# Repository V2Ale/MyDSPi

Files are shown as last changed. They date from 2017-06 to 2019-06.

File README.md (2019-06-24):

<!DOCTYPE html PUBLIC "-//W3C//DTD HTML 4.01//EN" "http://www.w3.org/TR/html4/strict.dtd">
<html>
<head>
  <meta content="text/html; charset=ISO-8859-1"
 http-equiv="content-type">
  <h1>MyDSPi</h1>
</head>
<body>

<br>
<div style="margin-left: 40px;">MyDSPi is an easy to
implement solution for audio processing and amplification with a
Raspberry Pi (2 and 3) audio output. <br>
It's intended to be a cost effective solution to make
active&nbsp;speakers.<br>
Electronic circuit is based on Analog Device ADAU1701 DSP and Texas
Instrument TPA3118 amplifier.<br>
<br>
More information  avaialble at <a href="http://mydspi;v2ale.com/?utm_source=Github&utm_medium=Link&utm_campaign=mainpage" >mydspi.v2ale.com</a>
<br>
</div>
<br style="font-weight: bold;">
<h3>Hardware description</h3>
<h4 style="margin-left: 40px; width: 1239px;">Overview : </h4>
<div style="margin-left: 40px;"><br>
<div style="margin-left: 40px;">MyDSPi is designed to be
compact and mounted over a Raspberry Pi 2 board. Hardware is split over
2 printed circuit boards stack one above the other.<br><br>
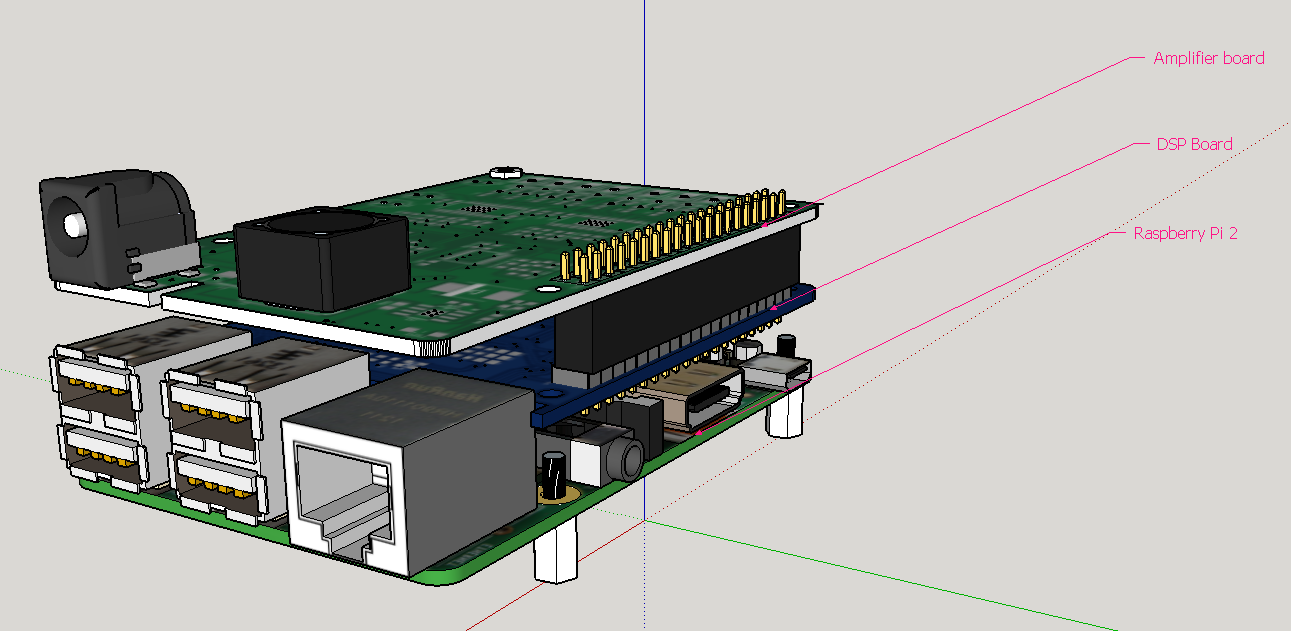
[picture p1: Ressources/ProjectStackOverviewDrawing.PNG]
Block diagram Amplifier
<br>
<br>
The first board is dedicated to DSP processing and Digital to Analog
signal convertion from Raspberry Pi audio output.&nbsp;Audio must
be output from Raspberry
Pi through I2S output pins.<br>
DSP is controlled by Raspberry Pi using I2C&nbsp; interface and
requires no
advanced DSP programming to have signal processed and can be easily
configured by editing a configuration file.<br>
The DSP work at fixed sampling frequency of 48000 Hz. <br>
Output channels are transmitted to the amplifier board through I2S
protocol.<br>
<br>
The second board host Digital to Analog converter that feed the
amplifier with analog signal for amplification. Power supply input
circuit is also located on this PCB, which can accept any supply
voltage from 12 to 24 volts to feed all system power supply (including
the Raspberry Pi).<br>
<br>
For more details about each board, please refer to :<br><br>
<ul>
<li><a href="https://github.com/V2Ale/MyDSPi/tree/master/Electronic/DSP%20Board/2.0">DSP Board page</a></li>
<li><a href="https://github.com/V2Ale/MyDSPi/tree/master/Electronic/Amplification%20Board">Amplifier board page</a></li>
</ul>
</div>
</div>
<br>
<h3><big>Software description</big></h3>
<div style="margin-left: 40px;">Once install is done the
MyDSPi software run at start-up to load default DSP parameters and then
load the parameters read from the configuration file.<br>
<br>
</div>
<h4>DSP Capabilities description</h4>
<br>
<div style="margin-left: 80px;">The default parameters of
the DSP are right now a 2 input / 2
output configuration with a default crossover and no EQ values loaded.
Parameter customization is done throught the MyDSPi.conf file and can
configure : <br>
<br>
<div style="margin-left: 40px;">- Input channels volume
controls<br>
- Input channels mute controls<br>
- 2 channels crossover<br>
- output channels Delay (up to 412 samples) <br>
- Ouput channel mute control<br>
- Ouput channel phase control<br>
- Output channel volume control<br>
</div>
</div>
<br>
<h3>Installation</h3>
Installation of &nbsp;MyDSPi is tested and developped for Linux
Raspbian Jessie distribution.<br>
<br>
The following step describes only the installation major steps. <br>

<ul>
<li>Setup I2C (<a href="https://learn.adafruit.com/adafruits-raspberry-pi-lesson-4-gpio-setup/configuring-i2c">
https://learn.adafruit.com/adafruits-raspberry-pi-lesson-4-gpio-setup/configuring-i2c</a>)<br>
</li>
<li>Setup I2S soundcard (following &nbsp;<a href="https://www.hifiberry.com/build/documentation/hifiberry-software-configuration/">https://www.hifiberry.com/build/documentation/hifiberry-software-configuration/</a>)<br>
</li>
<li>
 Run installation script (see https://github.com/V2Ale/MyDSPi/tree/master/Software/Install)<br>
 </li>
 </ul>

<h3>Configuration</h3>
To edit the configuration file, use the command :<br>
<pre>&nbsp;sudo nano /etc/default/MyDSPi.conf</pre>
For more details about configuration file rules, please refer to <span
 style="color: red;">https://github.com/V2Ale/MyDSPi/tree/master/Software/Install/config</span><br>
<br>
<h3>Roadmap</h3>
Support 5.1 configuration<br>
Support 7.1 configuration<br>
Support quadriphonic configuration<br>
&nbsp;<br>

</body>
</html>

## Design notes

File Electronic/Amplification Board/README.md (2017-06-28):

<!DOCTYPE html PUBLIC "-//W3C//DTD HTML 4.01//EN" "http://www.w3.org/TR/html4/strict.dtd">
<html>
<head>
  <meta content="text/html; charset=ISO-8859-1"
 http-equiv="content-type">
</head>
<body>
<h1>Amplifier and Power Supply Board</h1>
<h3>Overview</h3>
<br>
Amplifier and Power Supply board is the second PCB of this project that
can be stack with the DSP board. It's designed to host 2 set of
amplifiers and DAC, which can handle up to for 4 channels of
amplification. In addition, the board is used for power supply the
entire stack. <br>
<br style="color: red;">
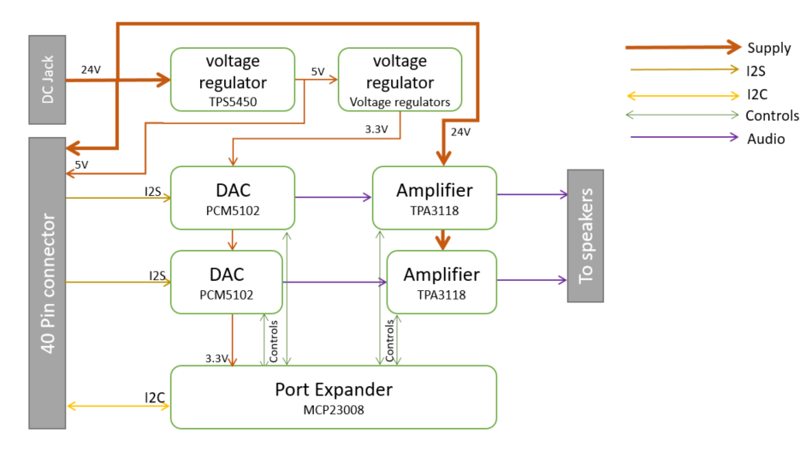
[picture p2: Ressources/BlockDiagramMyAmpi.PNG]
Block diagram Amplifier
<span style="color: red;"></span><br>
<br>
<h3>DAC</h3>
<br>
Digital to Analog conveters used for this board are PCM5102a (and
similar such as PCM5100). The
benefit of using PCM5102 DAC is that it does not requires the I2S
high frequency system clock (SCK) to work making routing between boards
much easier. <br>
Also, this component provides additionnal controls like demphasis, FIR
or IIR filter of output, format (I2S or Left justified) and soft mute.
Those controls are driven by a port expander with I2C interface that
allows end user to use this amplifier board for other designs. More
details on those controls can be found in the component datasheet. <br>
Last, this component
is readily cheap and available on the market (PCM5100 being pin to pin
compatible).<br>
<br>
<br>
<h3>Amplifier</h3>
&nbsp;<br>
The Texas Instrument TPA3118 amplifiers are stereo class D amplifiers
that can drive 2x30W into 8 Ohms load (with a 24V supply). It can
operate with a wide single operating voltage from 4.5V to 26V keeping
the power supply design simple. <br>
As audio input, the amplifier expect single ended audio which are
provided by DAC. All external controls (like gain) of the amplifier are
set constant except the amplifier mute which can be controlled thanks
to the port expander.<br>
Last, the amplifier integrates bad operating conditions (like
overtemperature, output short circuit) which are sent back to the
Faultz pins. Those pins are connected to the port expander and can be
monitored as well.<br>
<br>
<h3>Port Expander</h3>
<br>
As explain in previous parts, the port expander is in charge of
monitoring amplifier state and set DAC and amplifiers controls. The
part used for this task is very common MCP23008 from Microchip.<br>
<br>
<h3>Power Supply </h3>
<br>
The board do not have any power supply transformer and switch mode
power supply block design is outside the scope of this project. As a
result, a maximum of 26V voltage is expected at the DC jack terminal
connector. This voltage is directly used to feed the amplifiers and is
also converted down to a 5V supply voltage for all other boards
(including Raspberry Pi supply). &nbsp; <br>
<br>
<h3>Connectors </h3>
<br>
The&nbsp; 40 pin connector is used to connected to the DSP board
and get DSP output channels,&nbsp; I2C and amplifier mute command.
It also provides the supply rail voltage for the entire project.<br>
<br>
<span style="color: red;">[IMAGE DU SCHEMA DU CONNETEUR]</span><br>
<br>
<table style="text-align: left; width: 378px; height: 1216px;"
 border="1" cellpadding="2" cellspacing="2">
  <tbody>
    <tr>
      <td>Pin</td>
      <td>Name &nbsp; &nbsp; </td>
      <td>Description &nbsp; &nbsp; &nbsp; &nbsp;
&nbsp;</td>
    </tr>
    <tr>
      <td>1</td>
      <td>DC In</td>
      <td>Input Power supply is duplicated on this pin</td>
    </tr>
    <tr>
      <td>2</td>
      <td>DC In</td>
      <td>Input Power supply is duplicated on this pin</td>
    </tr>
    <tr>
      <td>3</td>
      <td>-</td>
      <td>Not used</td>
    </tr>
    <tr>
      <td>4</td>
      <td>SCL</td>
      <td>I2C Clock</td>
    </tr>
    <tr>
      <td>5</td>
      <td>-</td>
      <td>Not used</td>
    </tr>
    <tr>
      <td>6</td>
      <td>SDA</td>
      <td>I2C Data</td>
    </tr>
    <tr>
      <td>7</td>
      <td>Amp_mute</td>
      <td>Pin connected to Raspberry pi and amplifier mute pin.</td>
    </tr>
    <tr>
      <td>8</td>
      <td>-</td>
      <td>Not used</td>
    </tr>
    <tr>
      <td>9</td>
      <td>-</td>
      <td>Not used</td>
    </tr>
    <tr>
      <td>10</td>
      <td>-</td>
      <td>Not used</td>
    </tr>
    <tr>
      <td>11</td>
      <td>GND</td>
      <td>Ground</td>
    </tr>
    <tr>
      <td>12</td>
      <td>-</td>
      <td>Not used</td>
    </tr>
    <tr>
      <td>13</td>
      <td>-</td>
      <td>Not used</td>
    </tr>
    <tr>
      <td>14</td>
      <td>-</td>
      <td>Not used</td>
    </tr>
    <tr>
      <td>15</td>
      <td>-</td>
      <td>Not used</td>
    </tr>
    <tr>
      <td>16</td>
      <td>-</td>
      <td>Not used</td>
    </tr>
    <tr>
      <td>17</td>
      <td>GPO3</td>
      <td>DSP MPIO3 Output pin</td>
    </tr>
    <tr>
      <td>18</td>
      <td>GPO2</td>
      <td>DSP&nbsp;MPIO2 Output pin</td>
    </tr>
    <tr>
      <td>19</td>
      <td>GPO1</td>
      <td>DSP&nbsp;MPIO1 Output pin</td>
    </tr>
    <tr>
      <td>20</td>
      <td>DSPIN_SADATA0</td>
      <td>DSP I2S input pin 1</td>
    </tr>
    <tr>
      <td>21</td>
      <td>DSP_SDATA0</td>
      <td>DSP I2S output pin 1</td>
    </tr>
    <tr>
      <td>22</td>
      <td>DSP_BCK</td>
      <td>DSP I2S Bitclock output</td>
    </tr>
    <tr>
      <td>23</td>
      <td>DSP_SDATA1</td>
      <td>DSP I2S output pin 2</td>
    </tr>
    <tr>
      <td>24</td>
      <td>DSP_LRCK</td>
      <td>DSP I2S Bitclock output</td>
    </tr>
    <tr>
      <td>25</td>
      <td>ANALOG_IN_R</td>
      <td>DSP Analog input pin 1</td>
    </tr>
    <tr>
      <td>26</td>
      <td>ANALOG_IN_L</td>
      <td>DSP Analog input pin 2</td>
    </tr>
    <tr>
      <td>27</td>
      <td>AUDIO_OUT0</td>
      <td>DSP Analog output 1</td>
    </tr>
    <tr>
      <td>28</td>
      <td>GPO9</td>
      <td>DSP MPIO 9</td>
    </tr>
    <tr>
      <td>29</td>
      <td>AUDIO_OUT1</td>
      <td>DSP Analog output 2</td>
    </tr>
    <tr>
      <td>30</td>
      <td>GPO8</td>
      <td>DSP MPIO 8</td>
    </tr>
    <tr>
      <td>31</td>
      <td>AUDIO_OUT2</td>
      <td>DSP Analog output 3</td>
    </tr>
    <tr>
      <td>32</td>
      <td>AUDIO_OUT3</td>
      <td>DSP Analog output 4</td>
    </tr>
    <tr>
      <td>33</td>
      <td>-</td>
      <td>Not used</td>
    </tr>
    <tr>
      <td>34</td>
      <td>-</td>
      <td>Not used</td>
    </tr>
    <tr>
      <td>35</td>
      <td>GND</td>
      <td>Ground</td>
    </tr>
    <tr>
      <td>36</td>
      <td>GND</td>
      <td>Ground</td>
    </tr>
    <tr>
      <td>37</td>
      <td>5V</td>
      <td>5V power supply</td>
    </tr>
    <tr>
      <td>38</td>
      <td>GND</td>
      <td>Ground</td>
    </tr>
    <tr>
      <td>39</td>
      <td>5V</td>
      <td>5V power supply</td>
    </tr>
    <tr>
      <td>40</td>
      <td>5V</td>
      <td>5V power supply</td>
    </tr>
  </tbody>
</table>
<br>
<br>
</body>
</html>

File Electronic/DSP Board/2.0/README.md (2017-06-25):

DSP PCB

Power Supply

The PCB receives its power supply from the amplifier PCB which has the input DC jack socket and DC converters.

The 5V supply at input  is shared with the Raspberry Pi. From this supply, a 3.3V regulator on the board feed all components of this board.

Input channels
The DSP can process analog or digital (I2S) input, but only analog circuit is made available. Despite the presence of analog input circuit components routed in the 40 pin connecor, the project do not rely on it.
To use the board with the Raspberry Pi, the 3 wires of I2S are converted by a DAC (PCM5102a) and provided to DSP by the analog input.
The benefit of using PCM5102 DAC is that it does not requires the I2S system clock (SCK) to work. It's especially useful because the raspberry pi does not provide the SCK out of the box and it avoids useless painful struggle with the kernel.
Moreover, this component is readily cheap and available on the market (PCM5100 being pin to pin compatible). Extra functionality of this DAC such as filter type or soft mute are not used and not left to end user.

Output channels
 
The DSP can output analog or digital (I2S) signals. Both of them are available on this board but the amplifiers board is expecting I2S signal before amplification stage. If you whish to use the I2S output with other amplifier board, please mind that it does not output the SCK as well. This choice has been made because the DAC do not need it to operate normally and it avoid special care in the routing for this high speed clock.

I2S and clocks

Input and output I2S signals are working at fixed LRCK of 48kHz. The DSP is driven by a 24.576MHz clock. I2S LRCK and BCK at input and output of the DSP are connected together as required in the datasheet of the component.
It's not possible to run the DSP at other sampling frequency or with different outside clock without changing the routing of the board.

Connectors

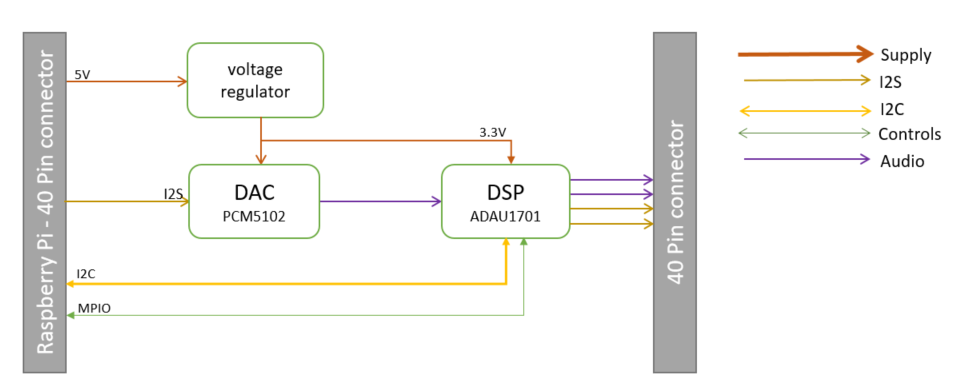
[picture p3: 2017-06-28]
Ressources/BlockDiagramMyDSPi.PNG

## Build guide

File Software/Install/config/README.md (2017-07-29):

Configuration
----------

MyDSPi configuration files needs to respect a few rules to allow to correct parameter loading.
All parametes are grouped into sections. Each sections can define a set of parameters which have their respective values. 

**Block diagram**

The audio block are linked together as follow to build the audio chain :

	audioinput -> input mute -> input volume -> EQ -> crossover -> delay -> phase -> mute -> volume

**Rules**
Writting a configuration needs to respect the following rules

 1.  Comments are ignored from the configuration lines.
 2.  A comment is everything that is after ';'character
 3.  A section is written in between brackets as    [SECTION]
 4.  To be valid a parameter must be followed by a value as parameter = value
 5.  Section, parameters and values must respect letter case
 6.  Each set of  parameter and its value must be written on the same line

**Sections**
The available sections are :

    [config]
    [Input1]
    [Input2]
    [Output1
    [Output2]
    [EQ1]
    [crossover]

----------

**Config section**

The input section is used to configure the input type of the DSP. It has one parameter : *audioinput*

It can take the following values

| Parameter | Value | Description  |
| --- | ---- | --- |
| audioinput | *digital* |  set DSP input to I2S signal|
| audioinput | *analog* | set DSP input to analog|
| audioinput | *tone* | This  force the input to be a twin sine tone signal (500 Hz and 5000 Hz)|

**Input sections**
There is one input section per input channel with 2 parameters in each section.

| Parameter | Value | Description  |
| --- | ---- | --- |
| *mute* | 0 or 1|  muted when it's value is 1, must be 0 otherwise|
| *volume* | -80.0 to 0.0|  control the input volume of the channel|

**Output sections**
There is one output section per output channel with 4 parameters in each section.

| Parameter | Value | Description  |
| --- | ---- | --- |
| *mute* | 0 or 1|  muted when it's value is 1, must be 0 otherwise|
| *volume* | -80.0 to 0.0|  control the input volume of the channel|
| *delay* | 1 to 412|  control the delay in samples of this channel |
| *phase*| 0 or 1|  control the output channel polarity. 1 to reverse polarity, 0 otherwise|

**EQ sections**
There are 14 EQ filters avaialble which can be configured independently. 

HSF for high shelf filter
LSF for low shelf filter
HPF for high pass filter (1st order Bessel)
LPF for Low pass filter (1st order Bessel)
peak for peak filter (parametric)

| Parameter | Value | Description  |
| --- | ---- | --- |
| *type* | HSF or LSF or HPF or LPF or peak| Defines the type of EQ |
| *F* | 20 to 20000| Set the corner frequency of the filter|
| *B* | -80.0 to 20.0|  Control boost factor of  peak, LSF and HSF filters.  |
| *Q* | 0.1 to 10.0|  Control Q-factor of  peak type EQ  |
| *B*| 0.0 to 3.0|  Control the S parameter of LSF and HSF filters.

**Crossover section**
       There is one crossover for both output channels made of 2nd order butterworth low-pass and high-pass filter.   
       
| Parameter | Value | Description  |
| --- | ---- | --- |
| *FLow* | between 20 and 20000 |  Defines the Low pass filter corner frequency. It must be lower than the FHigh value |
| *FHigh* | between 20 and 20000 |  Defines the High pass filter corner frequency. It must be greater than the FLow value

----------
**Config file Example**

	[config]

	audioinput=digital									

	[Input1]

	mute=1

	volume=-25										

	[Input2]										

	mute=0												

	volume=-25											

	[Output2]											

	phase=-1

	mute=1												

	delay=1												

	volume=0											

	[Output1]											

	phase=1

	mute=1												

	delay=1												

	volume=-6											

	[EQ1]												

	F=125												

	B=-2.8												

	Q=1.41													

	Type=peak											

	[EQ2]

	F=5000												

	B=-2												

	Q=4													

	Type=peak	

	[EQ3]

	F=2200

	B=-2

	S=2

	Type=HSF

	[crossover]											

	FLow = 2800										

	FHigh = 3000

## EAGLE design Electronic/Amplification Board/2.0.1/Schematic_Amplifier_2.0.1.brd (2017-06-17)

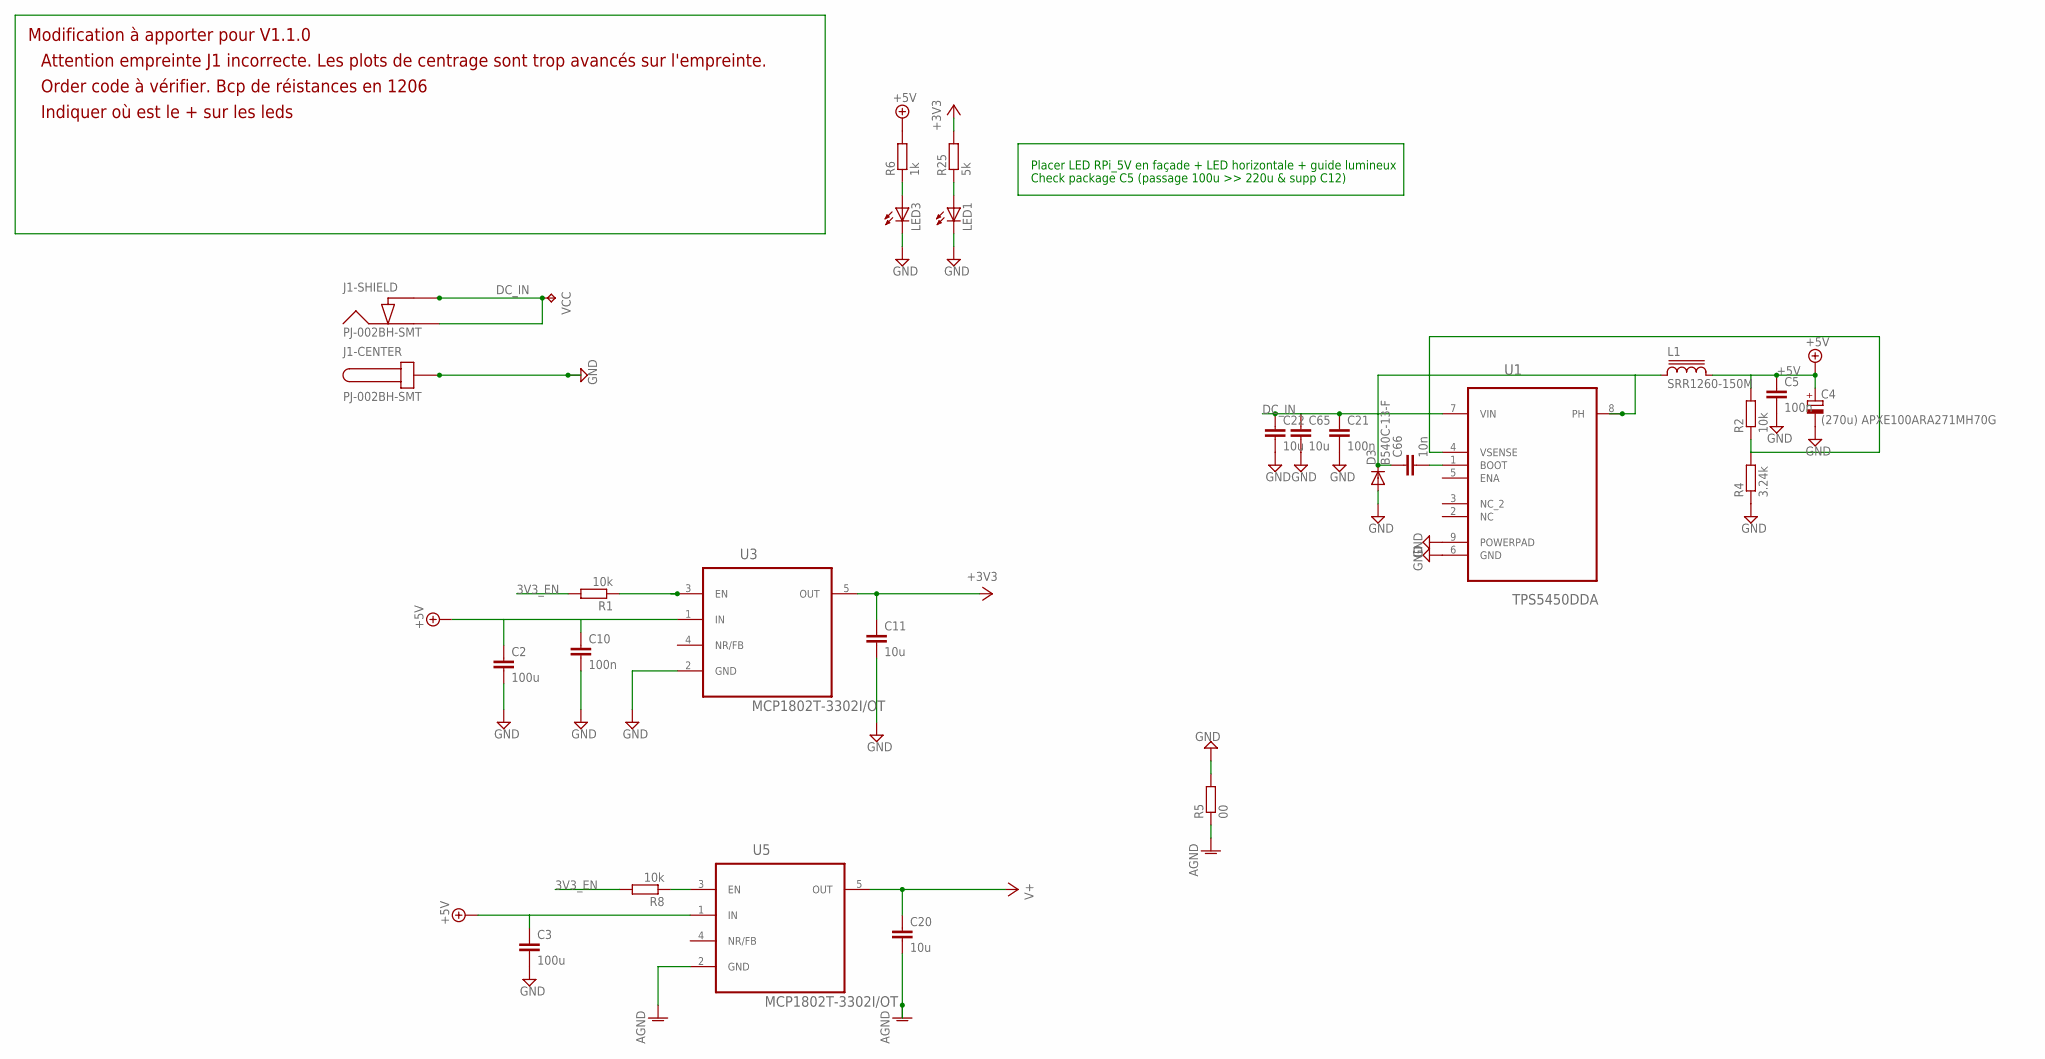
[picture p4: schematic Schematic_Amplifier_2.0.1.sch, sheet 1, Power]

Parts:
C2, C3: 100u; C1206
C4: (270u) APXE100ARA271MH70G; 175TMP-0810
C5, C10, C21: 100n; C0603
C11, C20, C22, C65: 10u; C0805
C66: 10n; C0603
D3: B540C-13-F; SMC
J1: PJ-002BH-SMT; 002BH-SMT
L1: SRR1260-150M; SRR1280
LED1: LEDSML0603; SML0603
LED3: LEDSML1206; SML1206
R1, R2, R8: 10k; R0603
R4: 3.24k; R0603
R5: 00; R0603
R6: 1k; R0603
R25: 5k; R0603
U1: TPS5450DDA; SOIC127P600X170-9N
U3, U5: MCP1802T-3302I/OT; SOT95P280X145-5N
VCC: TPTP20R; TP20R

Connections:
3V3_EN: R1.2, R8.2; also elsewhere on the board
+3V3: C11.1, R25.2, U3.5 (OUT); also elsewhere on the board
+5V: C2.1, C3.1, C4.+, C5.1, C10.1, L1.2, R2.2, R6.2, U3.1 (IN), U5.1 (IN); also elsewhere on the board
AGND: C20.2, R5.1, U5.2 (GND); also elsewhere on the board
DC_IN: C21.1, C22.1, C65.1, J1.2, J1.3, U1.7 (VIN), VCC.TP; also elsewhere on the board
GND: C2.2, C3.2, C4.-, C5.2, C10.2, C11.2, C21.2, C22.2, C65.2, D3.A, J1.CENTER1 (1), J1.CENTER2 (1), LED1.C, LED3.C, R4.1, R5.2, U1.6 (GND), U1.9 (POWERPAD), U3.2 (GND); also elsewhere on the board
unnamed: R1.1, U3.3 (EN)
unnamed: LED1.A, R25.1
unnamed: C66.2, U1.1 (BOOT)
unnamed: LED3.A, R6.1
unnamed: R8.1, U5.3 (EN)
unnamed: C66.1, D3.C, L1.1, U1.8 (PH)
unnamed: R2.1, R4.2, U1.4 (VSENSE)
V+: C20.1, U5.5 (OUT); also elsewhere on the board

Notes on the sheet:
Placer LED RPi_5V en façade + LED horizontale + guide lumineux
Check package C5 (passage 100u >> 220u & supp C12)
Attention empreinte J1 incorrecte. Les plots de centrage sont trop avancés sur l'empreinte.
Modification à apporter pour V1.1.0
Order code à vérifier. Bcp de réistances en 1206
Indiquer où est le + sur les leds

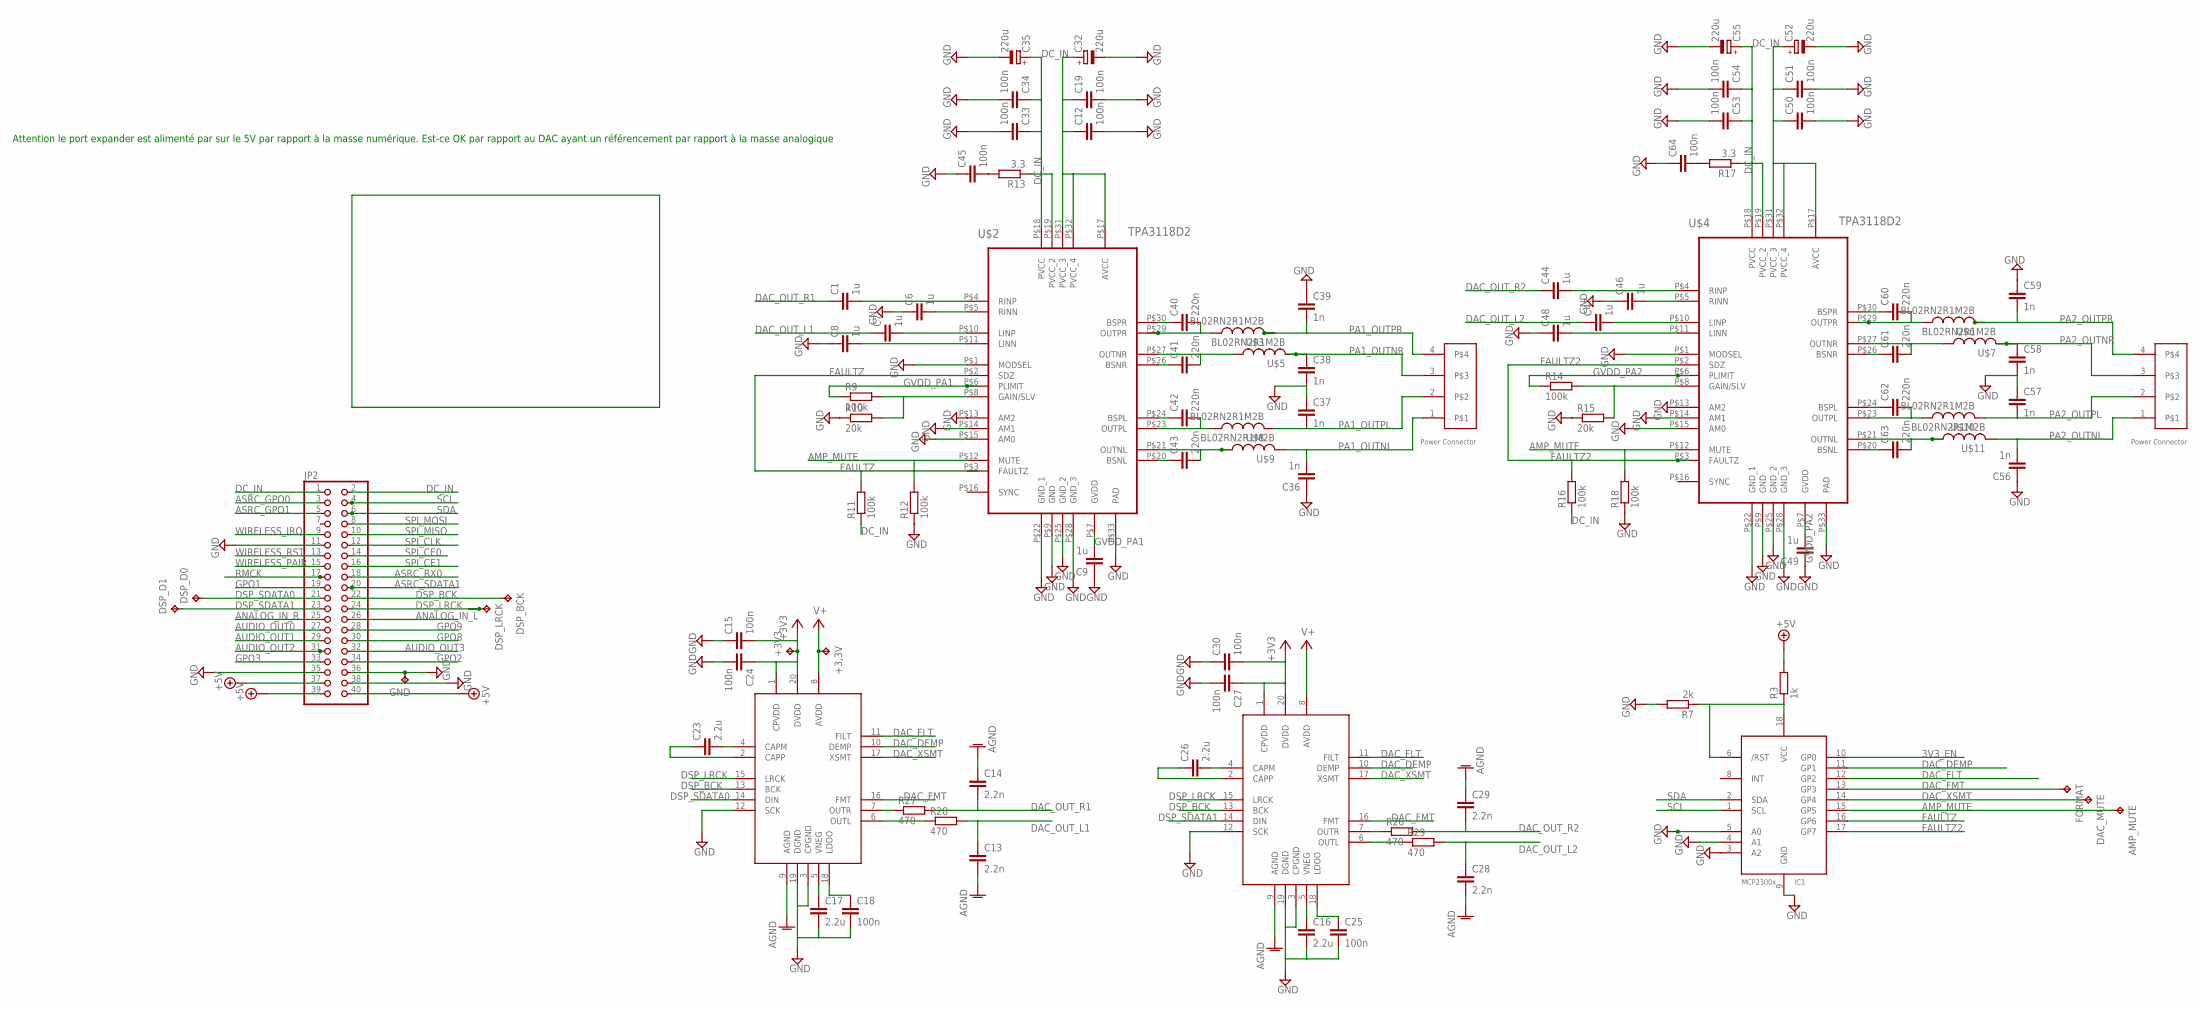
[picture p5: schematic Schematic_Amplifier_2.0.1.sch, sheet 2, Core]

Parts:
+3,3V, +3V3: TPTP10R; TP10R
AMP_MUTE: TPTP08R; TP08R
C1, C6, C7, C8, C9, C44, C46, C47, C48, C49: 1u; C0603
C12, C15, C18, C19, C24, C25, C27, C30, C33, C34, C45, C50, C51, C53, C54, C64: 100n; C0603
C13, C14, C28, C29: 2.2n; C0603
C16, C17, C23, C26: 2.2u; C0603
C32, C35, C52, C55: 220u; E2,5-6
C36, C37, C38, C39, C56, C57, C58, C59: 1n; C0603
C40, C41, C42, C43, C60, C61, C62, C63: 220n; C0603
DAC0, DAC1: PCM5102A; 20L-TSSOP
DAC_MUTE: TPTP08R; TP08R
DSP_BCK: TPTP08R; TP08R
DSP_D0, DSP_D1: TPTP08R; TP08R
DSP_LRCK: TPTP08R; TP08R
FORMAT: TPTP08R; TP08R
GND: TPTP19SQ; TP19SQ
IC1: MCP23008/SO; SO18W
JP2: PINHD-2X20; 2X20
R3: 1k; R0603
R7: 2k; R0603
R9, R11, R12, R14, R16, R18: 100k; R0603
R10, R15: 20k; R0603
R13, R17: 3.3; R0603
R26, R27, R28, R29: 470; R0603
U$1, U$12: 1-1123723-4; POWER_CON_HEADER
U$2, U$4: TPA3118D2; TSSOP32
U$3, U$5, U$6, U$7, U$8, U$9, U$10, U$11: BL02RN2R1M2B; FB

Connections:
3V3_EN: IC1.10 (GP0); also elsewhere on the board
$OUTR: DAC0.7 (OUTR), R26.1
+3V3: +3V3.TP, C15.2, C24.1, C27.1, C30.2, DAC0.1 (CPVDD), DAC0.20 (DVDD), DAC1.1 (CPVDD), DAC1.20 (DVDD); also elsewhere on the board
+5V: JP2.37, JP2.39, JP2.40, R3.2; also elsewhere on the board
AGND: C13.2, C14.1, C28.2, C29.1, DAC0.9 (AGND), DAC1.9 (AGND); also elsewhere on the board
AMP_MUTE: AMP_MUTE.TP, IC1.15 (GP5), R12.2, R18.2, U$2.P$12 (MUTE), U$4.P$12 (MUTE)
ANALOG_IN_L: JP2.26
ANALOG_IN_R: JP2.25
ASRC_GPO0: JP2.3
ASRC_GPO1: JP2.5
ASRC_RX0: JP2.18
ASRC_SDATA1: JP2.20
AUDIO_OUT0: JP2.27
AUDIO_OUT1: JP2.29
AUDIO_OUT2: JP2.31
AUDIO_OUT3: JP2.32
DAC_DEMP: DAC0.10 (DEMP), DAC1.10 (DEMP), IC1.11 (GP1)
DAC_FLT: DAC0.11 (FILT), DAC1.11 (FILT), IC1.12 (GP2)
DAC_FMT: DAC0.16 (FMT), DAC1.16 (FMT), FORMAT.TP, IC1.13 (GP3)
DAC_OUT_L1: C7.1, C13.1, R28.2
DAC_OUT_L2: C28.1, C47.1, R29.2
DAC_OUT_R1: C1.1, C14.2, R27.2
DAC_OUT_R2: C29.2, C44.1, R26.2
DAC_XSMT: DAC0.17 (XSMT), DAC1.17 (XSMT), DAC_MUTE.TP, IC1.14 (GP4)
DC_IN: C12.1, C19.1, C32.+, C33.1, C34.1, C35.+, C50.1, C51.1, C52.+, C53.1, C54.1, C55.+, JP2.1, JP2.2, R11.1, R13.1, R16.1, R17.1, U$2.P$17 (AVCC), U$2.P$18 (PVCC), U$2.P$31 (PVCC_3), U$2.P$32 (PVCC_4), U$4.P$17 (AVCC), U$4.P$18 (PVCC), U$4.P$31 (PVCC_3), U$4.P$32 (PVCC_4); also elsewhere on the board
DSP_BCK: DAC0.13 (BCK), DAC1.13 (BCK), DSP_BCK.TP, JP2.22
DSP_LRCK: DAC0.15 (LRCK), DAC1.15 (LRCK), DSP_LRCK.TP, JP2.24
DSP_SDATA0: DAC1.14 (DIN), DSP_D0.TP, JP2.21
DSP_SDATA1: DAC0.14 (DIN), DSP_D1.TP, JP2.23
FAULTZ: IC1.16 (GP6), R11.2, U$2.P$2 (SDZ), U$2.P$3 (FAULTZ)
FAULTZ2: IC1.17 (GP7), R16.2, U$4.P$2 (SDZ), U$4.P$3 (FAULTZ)
GND: C6.1, C8.1, C9.1, C12.2, C15.1, C16.2, C17.2, C18.2, C19.2, C24.2, C25.2, C27.2, C30.1, C32.-, C33.2, C34.2, C35.-, C36.1, C37.1, C38.2, C39.1, C45.1, C46.1, C48.1, C49.1, C50.2, C51.2, C52.-, C53.2, C54.2, C55.-, C56.1, C57.1, C58.2, C59.1, C64.1, DAC0.3 (CPGND), DAC0.12 (SCK), DAC0.19 (DGND), DAC1.3 (CPGND), DAC1.12 (SCK), DAC1.19 (DGND), GND.TP, IC1.3 (A2), IC1.4 (A1), IC1.5 (A0), IC1.9 (GND), JP2.11, JP2.35, JP2.36, JP2.38, R7.2, R10.1, R12.1, R15.1, R18.1, U$2.P$1 (MODSEL), U$2.P$9 (GND), U$2.P$13 (AM2), U$2.P$14 (AM1), U$2.P$15 (AM0), U$2.P$22 (GND_1), U$2.P$25 (GND_2), U$2.P$28 (GND_3), U$2.P$33 (PAD), U$4.P$1 (MODSEL), U$4.P$9 (GND), U$4.P$13 (AM2), U$4.P$14 (AM1), U$4.P$15 (AM0), U$4.P$22 (GND_1), U$4.P$25 (GND_2), U$4.P$28 (GND_3), U$4.P$33 (PAD); also elsewhere on the board
GPO1: JP2.19
GPO2: JP2.34
GPO3: JP2.33
GPO8: JP2.30
GPO9: JP2.28
GVDD_PA1: C9.2, R9.1, U$2.P$6 (PLIMIT), U$2.P$7 (GVDD)
GVDD_PA2: C49.2, R14.1, U$4.P$6 (PLIMIT), U$4.P$7 (GVDD)
unnamed: C1.2, U$2.P$4 (RINP)
unnamed: IC1.6 (/RST), IC1.18 (VCC), R3.1, R7.1
unnamed: C6.2, U$2.P$5 (RINN)
unnamed: C7.2, U$2.P$10 (LINP)
unnamed: C8.2, U$2.P$11 (LINN)
unnamed: R9.2, R10.2, U$2.P$8 (GAIN/SLV)
unnamed: C41.2, U$2.P$27 (OUTNR), U$5.P$1 (1)
unnamed: C40.2, U$2.P$29 (OUTPR), U$3.P$1 (1)
unnamed: C42.2, U$2.P$23 (OUTPL), U$8.P$1 (1)
unnamed: C43.2, U$2.P$21 (OUTNL), U$9.P$1 (1)
unnamed: C44.2, U$4.P$4 (RINP)
unnamed: C40.1, U$2.P$30 (BSPR)
unnamed: C17.1, DAC1.5 (VNEG)
unnamed: C23.2, DAC1.4 (CAPM)
unnamed: C45.2, R13.2
unnamed: C46.2, U$4.P$5 (RINN)
unnamed: C47.2, U$4.P$10 (LINP)
unnamed: C41.1, U$2.P$26 (BSNR)
unnamed: C42.1, U$2.P$24 (BSPL)
unnamed: C43.1, U$2.P$20 (BSNL)
unnamed: C48.2, U$4.P$11 (LINN)
unnamed: DAC1.7 (OUTR), R27.1
unnamed: DAC1.6 (OUTL), R28.1
unnamed: C16.1, DAC0.5 (VNEG)
unnamed: C25.1, DAC0.18 (LDOO)
unnamed: C26.2, DAC0.4 (CAPM)
unnamed: C18.1, DAC1.18 (LDOO)
unnamed: C26.1, DAC0.2 (CAPP)
unnamed: R14.2, R15.2, U$4.P$8 (GAIN/SLV)
unnamed: C23.1, DAC1.2 (CAPP)
unnamed: DAC0.6 (OUTL), R29.1
unnamed: C61.2, U$4.P$27 (OUTNR), U$7.P$1 (1)
unnamed: C60.2, U$4.P$29 (OUTPR), U$6.P$1 (1)
unnamed: C62.2, U$4.P$23 (OUTPL), U$10.P$1 (1)
unnamed: C63.2, U$4.P$21 (OUTNL), U$11.P$1 (1)
unnamed: C60.1, U$4.P$30 (BSPR)
unnamed: C61.1, U$4.P$26 (BSNR)
unnamed: C62.1, U$4.P$24 (BSPL)
unnamed: C63.1, U$4.P$20 (BSNL)
unnamed: C64.2, R17.2
PA1_OUTNL: C36.2, U$1.1, U$9.P$2 (2)
PA1_OUTNR: C38.1, U$1.3, U$5.P$2 (2)
PA1_OUTPL: C37.2, U$1.2, U$8.P$2 (2)
PA1_OUTPR: C39.2, U$1.4, U$3.P$2 (2)
PA2_OUTNL: C56.2, U$11.P$2 (2), U$12.1
PA2_OUTNR: C58.1, U$7.P$2 (2), U$12.3
PA2_OUTPL: C57.2, U$10.P$2 (2), U$12.2
PA2_OUTPR: C59.2, U$6.P$2 (2), U$12.4
RMCK: JP2.17
SCL: IC1.1 (SCL), JP2.4
SDA: IC1.2 (SDA), JP2.6
SPI_CE0: JP2.14
SPI_CE1: JP2.16
SPI_CLK: JP2.12
SPI_MISO: JP2.10
SPI_MOSI: JP2.8
V+: +3,3V.TP, DAC0.8 (AVDD), DAC1.8 (AVDD); also elsewhere on the board
WIRELESS_IRQ: JP2.9
WIRELESS_PAIR: JP2.15
WIRELESS_RST: JP2.13

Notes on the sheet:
Attention le port expander est alimenté par sur le 5V par rapport à la masse numérique. Est-ce OK par rapport au DAC ayant un référencement par rapport à la masse analogique

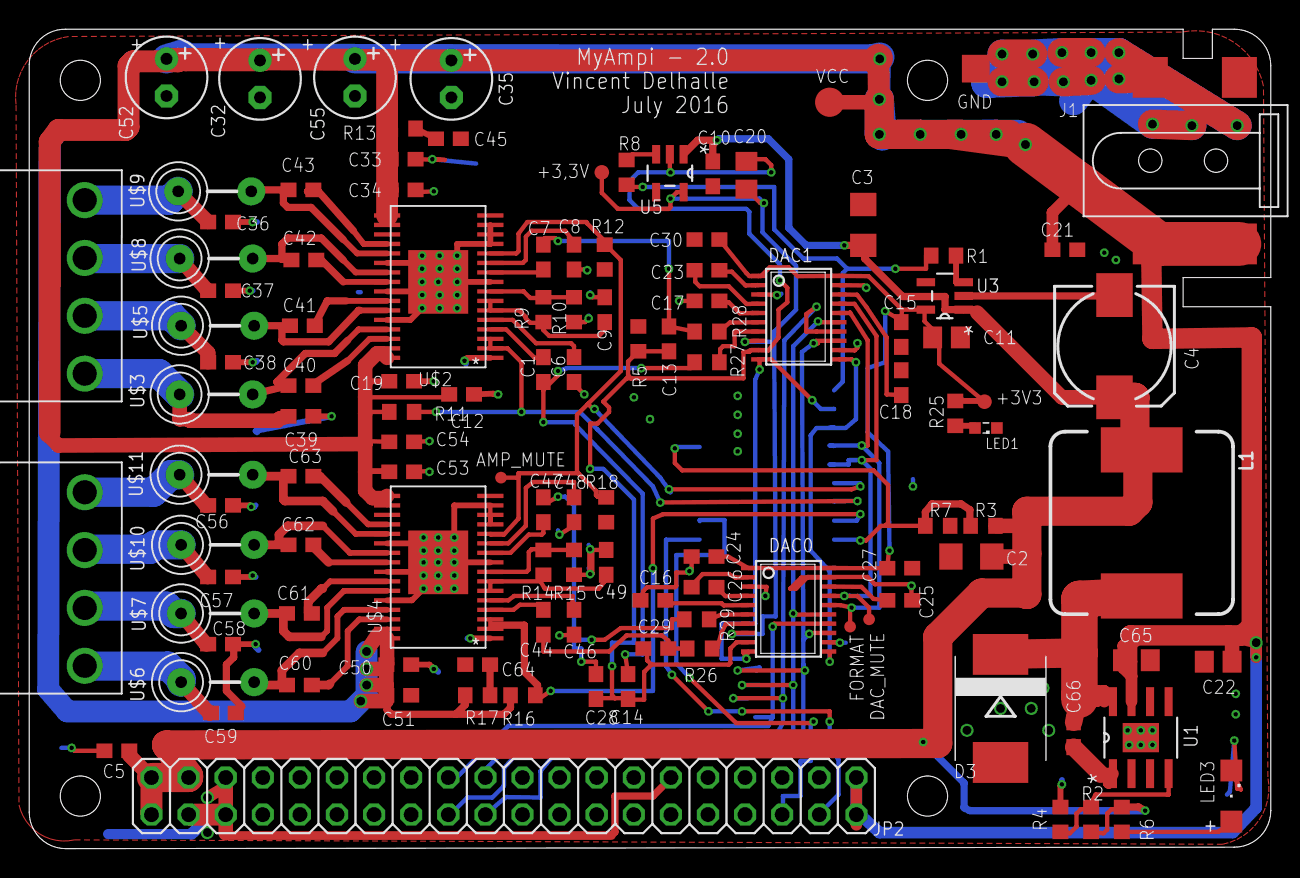
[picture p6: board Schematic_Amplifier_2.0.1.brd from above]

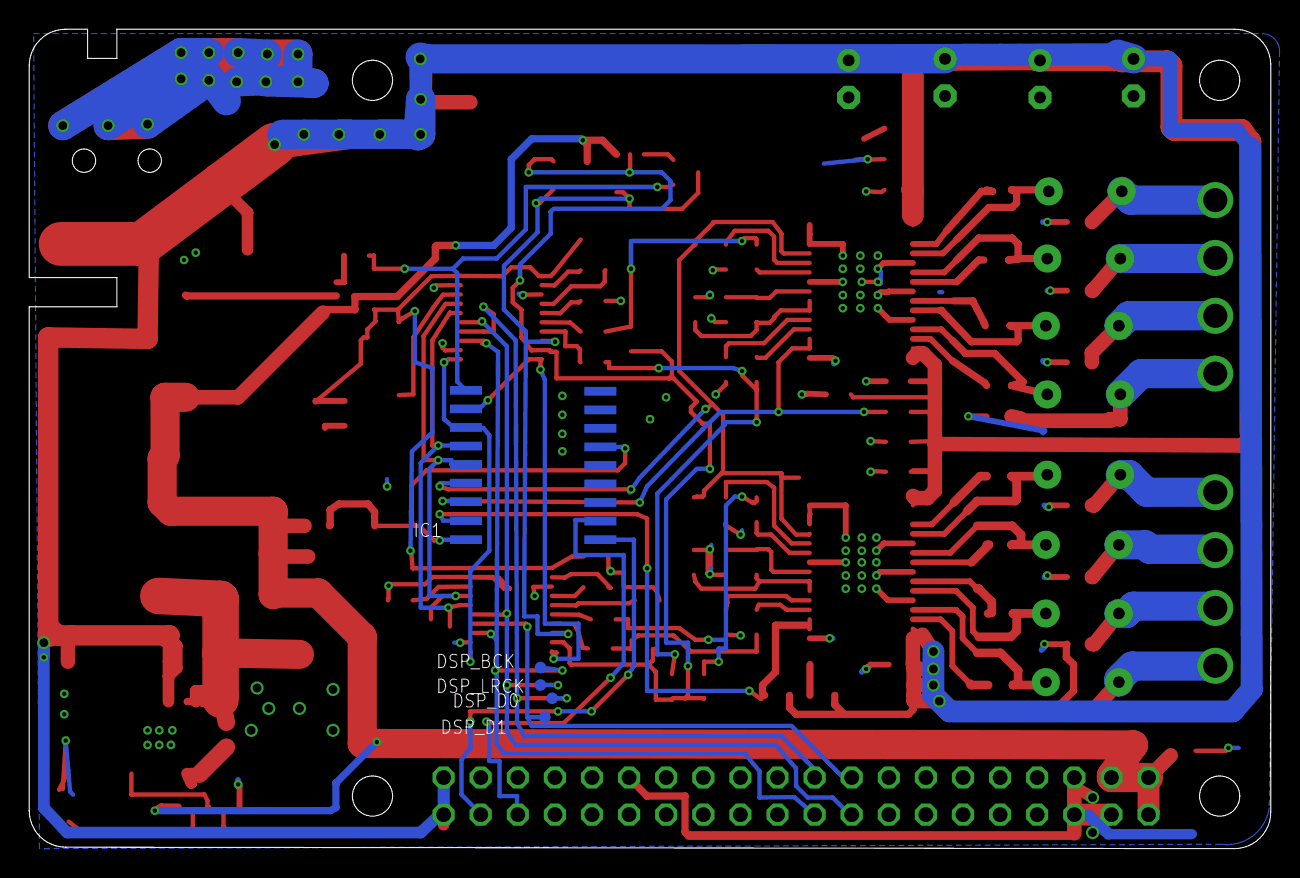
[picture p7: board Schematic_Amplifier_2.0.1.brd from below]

Board: 2 copper layers, 85.0 x 56.1 mm, 123 parts (5 on the bottom side), 82 nets.

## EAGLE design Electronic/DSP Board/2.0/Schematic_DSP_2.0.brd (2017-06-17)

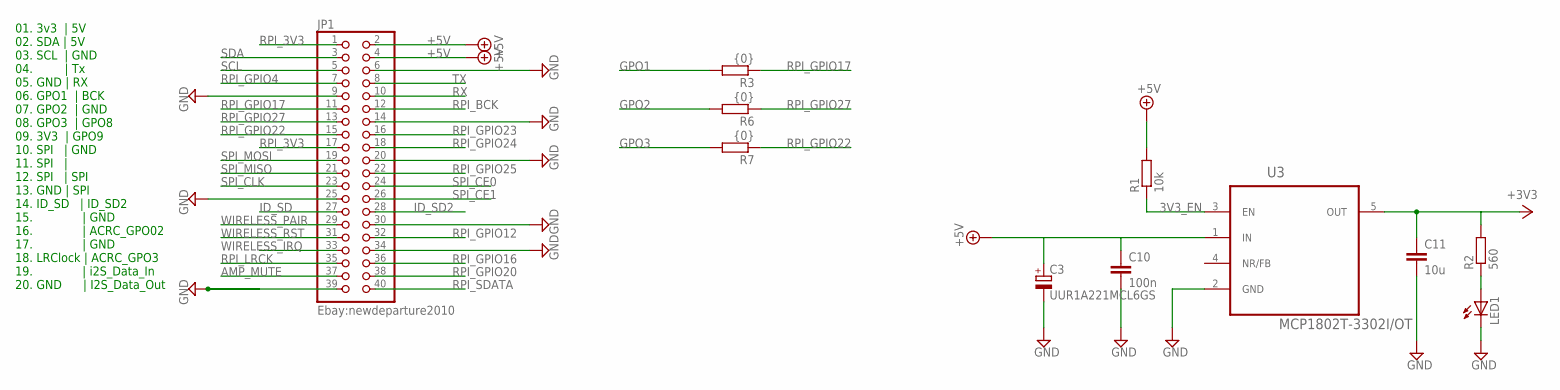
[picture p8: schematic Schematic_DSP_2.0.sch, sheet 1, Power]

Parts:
C3: UUR1A221MCL6GS; UD-6,3X7,7_NICHICON
C10: 100n; C0603
C11: 10u; C0805
JP1: Ebay:newdeparture2010; 2X20
LED1: LEDSML0603; SML0603
R1: 10k; R0603
R2: 560; R0603
R3, R6, R7: {0}; R0603
U3: MCP1802T-3302I/OT; SOT95P280X145-5N

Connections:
3V3_EN: R1.1, U3.3 (EN)
+3V3: C11.1, R2.2, U3.5 (OUT); also elsewhere on the board
+5V: C3.+, C10.1, JP1.2, JP1.4, R1.2, U3.1 (IN); also elsewhere on the board
AMP_MUTE: JP1.37; also elsewhere on the board
GND: C3.-, C10.2, C11.2, JP1.6, JP1.9, JP1.14, JP1.20, JP1.25, JP1.30, JP1.34, JP1.39, LED1.C, U3.2 (GND); also elsewhere on the board
GPO1: R3.2; also elsewhere on the board
GPO2: R6.2; also elsewhere on the board
GPO3: R7.2; also elsewhere on the board
ID_SD: JP1.27
ID_SD2: JP1.28
unnamed: LED1.A, R2.1
RPI_3V3: JP1.1, JP1.17
RPI_BCK: JP1.12; also elsewhere on the board
RPI_GPIO4: JP1.7
RPI_GPIO12: JP1.32
RPI_GPIO16: JP1.36
RPI_GPIO17: JP1.11, R3.1
RPI_GPIO20: JP1.38
RPI_GPIO22: JP1.15, R7.1
RPI_GPIO23: JP1.16
RPI_GPIO24: JP1.18
RPI_GPIO25: JP1.22
RPI_GPIO27: JP1.13, R6.1
RPI_LRCK: JP1.35; also elsewhere on the board
RPI_SDATA: JP1.40; also elsewhere on the board
RX: JP1.10
SCL: JP1.5; also elsewhere on the board
SDA: JP1.3; also elsewhere on the board
SPI_CE0: JP1.24
SPI_CE1: JP1.26
SPI_CLK: JP1.23
SPI_MISO: JP1.21
SPI_MOSI: JP1.19
TX: JP1.8
WIRELESS_IRQ: JP1.33
WIRELESS_PAIR: JP1.29
WIRELESS_RST: JP1.31

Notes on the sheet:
01. 3v3 | 5V 02. SDA | 5V 03. SCL | GND 04. | Tx 05. GND | RX 06. GPO1 | BCK 07. GPO2 | GND 08. GPO3 | GPO8 09. 3V3 | GPO9 10. SPI | GND 11. SPI | 12. SPI | SPI 13. GND | SPI 14. ID_SD | ID_SD2 15. | GND 16. | ACRC_GPO02 17. | GND 18. LRClock | ACRC_GPO3 19. | i2S_Data_In 20. GND | I2S_Data_Out

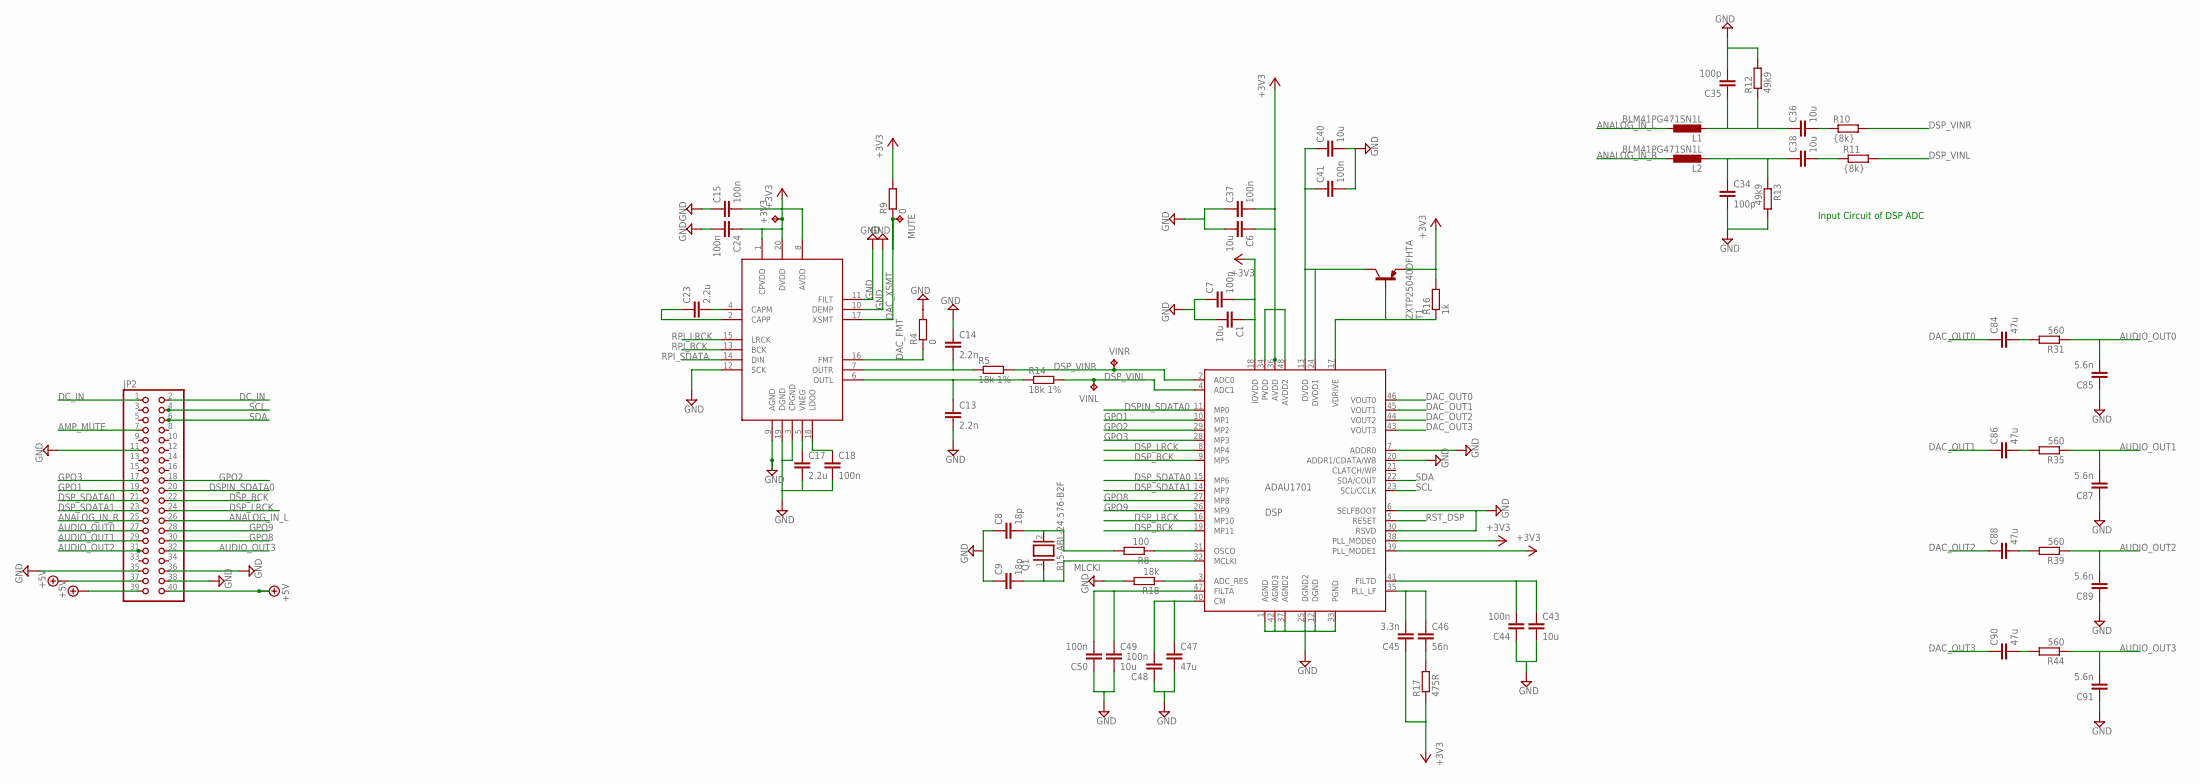
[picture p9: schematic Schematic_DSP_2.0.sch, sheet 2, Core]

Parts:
+3V3: TPTP10R; TP10R
C1, C6, C36, C38, C40, C43, C49: 10u; C0805
C7, C15, C18, C24, C37, C41, C44, C48, C50: 100n; C0603
C8, C9: 18p; C0603
C13, C14: 2.2n; C0603
C17, C23: 2.2u; C0603
C34, C35: 100p; C0603
C45: 3.3n; C0603
C46: 56n; C0603
C47, C84, C86, C88, C90: 47u; C0805
C85, C87, C89, C91: 5.6n; C0603
DAC1: PCM5102A; 20L-TSSOP
DSP: ADAU1701; PQFP48
JP2: PINHD-2X20; 2X20
L1, L2: BLM41PG471SN1L; L4532M
MUTE: TPTP10R; TP10R
Q1: 815-ABL-24.576-B2F; QS
R4, R9: 0; R0603
R5, R14: 18k 1%; R0603
R8: 100; R0603
R10, R11: {8k}; R0603
R12, R13: 49k9; R0603
R16: 1k; R0603
R17: 475R; R0603
R18: 18k; R0603
R31, R35, R39, R44: 560; R0603
T1: ZXTP25040DFHTA; SOT23-BEC
VINL: TPTP14R; TP14R
VINR: TPTP14R; TP14R

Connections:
+3V3: +3V3.TP, C1.1, C6.1, C7.2, C15.2, C24.1, C37.2, C45.1, DAC1.1 (CPVDD), DAC1.8 (AVDD), DAC1.20 (DVDD), DSP.18 (IOVDD), DSP.34 (PVDD), DSP.36 (AVDD), DSP.38 (PLL_MODE0), DSP.39 (PLL_MODE1), DSP.48 (AVDD2), R9.2, R16.2, R17.1, T1.E; also elsewhere on the board
+5V: JP2.37, JP2.39, JP2.40; also elsewhere on the board
AMP_MUTE: JP2.7; also elsewhere on the board
ANALOG_IN_L: JP2.26, L1.1
ANALOG_IN_R: JP2.25, L2.1
AUDIO_OUT0: C85.2, JP2.27, R31.1
AUDIO_OUT1: C87.2, JP2.29, R35.1
AUDIO_OUT2: C89.2, JP2.31, R39.1
AUDIO_OUT3: C91.2, JP2.32, R44.1
CM: C47.1, C48.2, DSP.40 (CM)
DAC_FMT: DAC1.16 (FMT), R4.1
DAC_OUT0: C84.1, DSP.46 (VOUT0)
DAC_OUT1: C86.1, DSP.45 (VOUT1)
DAC_OUT2: C88.1, DSP.44 (VOUT2)
DAC_OUT3: C90.1, DSP.43 (VOUT3)
DAC_OUTL: C13.1, DAC1.6 (OUTL), R14.1
DAC_OUTR: C14.2, DAC1.7 (OUTR), R5.1
DAC_XSMT: DAC1.17 (XSMT), MUTE.TP, R9.1
DC_IN: JP2.1, JP2.2
DSPIN_SDATA0: DSP.11 (MP0), JP2.20
DSP_BCK: DSP.9 (MP5), DSP.19 (MP11), JP2.22
DSP_LRCK: DSP.8 (MP4), DSP.16 (MP10), JP2.24
DSP_SDATA0: DSP.15 (MP6), JP2.21
DSP_SDATA1: DSP.14 (MP7), JP2.23
DSP_VINL: DSP.4 (ADC1), R11.2, R14.2, VINL.TP
DSP_VINR: DSP.2 (ADC0), R5.2, R10.2, VINR.TP
FILTA: C49.1, C50.2, DSP.47 (FILTA)
FILTD: C43.1, C44.2, DSP.41 (FILTD)
GND: C1.2, C6.2, C7.1, C8.1, C9.1, C13.2, C14.1, C15.1, C17.2, C18.2, C24.2, C34.2, C35.2, C37.1, C40.2, C41.2, C43.2, C44.1, C47.2, C48.1, C49.2, C50.1, C85.1, C87.1, C89.1, C91.1, DAC1.3 (CPGND), DAC1.9 (AGND), DAC1.10 (DEMP), DAC1.11 (FILT), DAC1.12 (SCK), DAC1.19 (DGND), DSP.1 (AGND), DSP.6 (SELFBOOT), DSP.7 (ADDR0), DSP.12 (DGND), DSP.20 (ADDR1/CDATA/WB), DSP.25 (DGND2), DSP.30 (RSVD), DSP.33 (PGND), DSP.37 (AGND2), DSP.42 (AGND3), JP2.11, JP2.35, JP2.36, JP2.38, R4.2, R12.2, R13.2, R18.2; also elsewhere on the board
GPO1: DSP.10 (MP1), JP2.19; also elsewhere on the board
GPO2: DSP.29 (MP2); also elsewhere on the board
GPO3: DSP.28 (MP3); also elsewhere on the board
GPO8: DSP.27 (MP8), JP2.30
GPO9: DSP.26 (MP9), JP2.28
MLCKI: C9.2, DSP.32 (MCLKI), Q1.1
unnamed: C40.1, C41.1, DSP.13 (DVDD), DSP.24 (DVDD1), T1.C
unnamed: DSP.31 (OSCO), R8.1
unnamed: DSP.17 (VDRIVE), R16.1, T1.B
unnamed: C8.2, Q1.2, R8.2
unnamed: C46.2, R17.2
unnamed: C17.1, DAC1.5 (VNEG)
unnamed: C23.2, DAC1.4 (CAPM)
unnamed: DSP.3 (ADC_RES), R18.1
unnamed: C36.2, R10.1
unnamed: C18.1, DAC1.18 (LDOO)
unnamed: C38.2, R11.1
unnamed: C23.1, DAC1.2 (CAPP)
unnamed: C34.1, C38.1, L2.2, R13.1
unnamed: C35.1, C36.1, L1.2, R12.1
unnamed: C84.2, R31.2
unnamed: C86.2, R35.2
unnamed: C88.2, R39.2
unnamed: C90.2, R44.2
PLL_LF: C45.2, C46.1, DSP.35 (PLL_LF)
RPI_BCK: DAC1.13 (BCK); also elsewhere on the board
RPI_LRCK: DAC1.15 (LRCK); also elsewhere on the board
RPI_SDATA: DAC1.14 (DIN); also elsewhere on the board
RST_DSP: DSP.5 (RESET)
SCL: DSP.23 (SCL/CCLK), JP2.4; also elsewhere on the board
SDA: DSP.22 (SDA/COUT), JP2.6; also elsewhere on the board

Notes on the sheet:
Input Circuit of DSP ADC

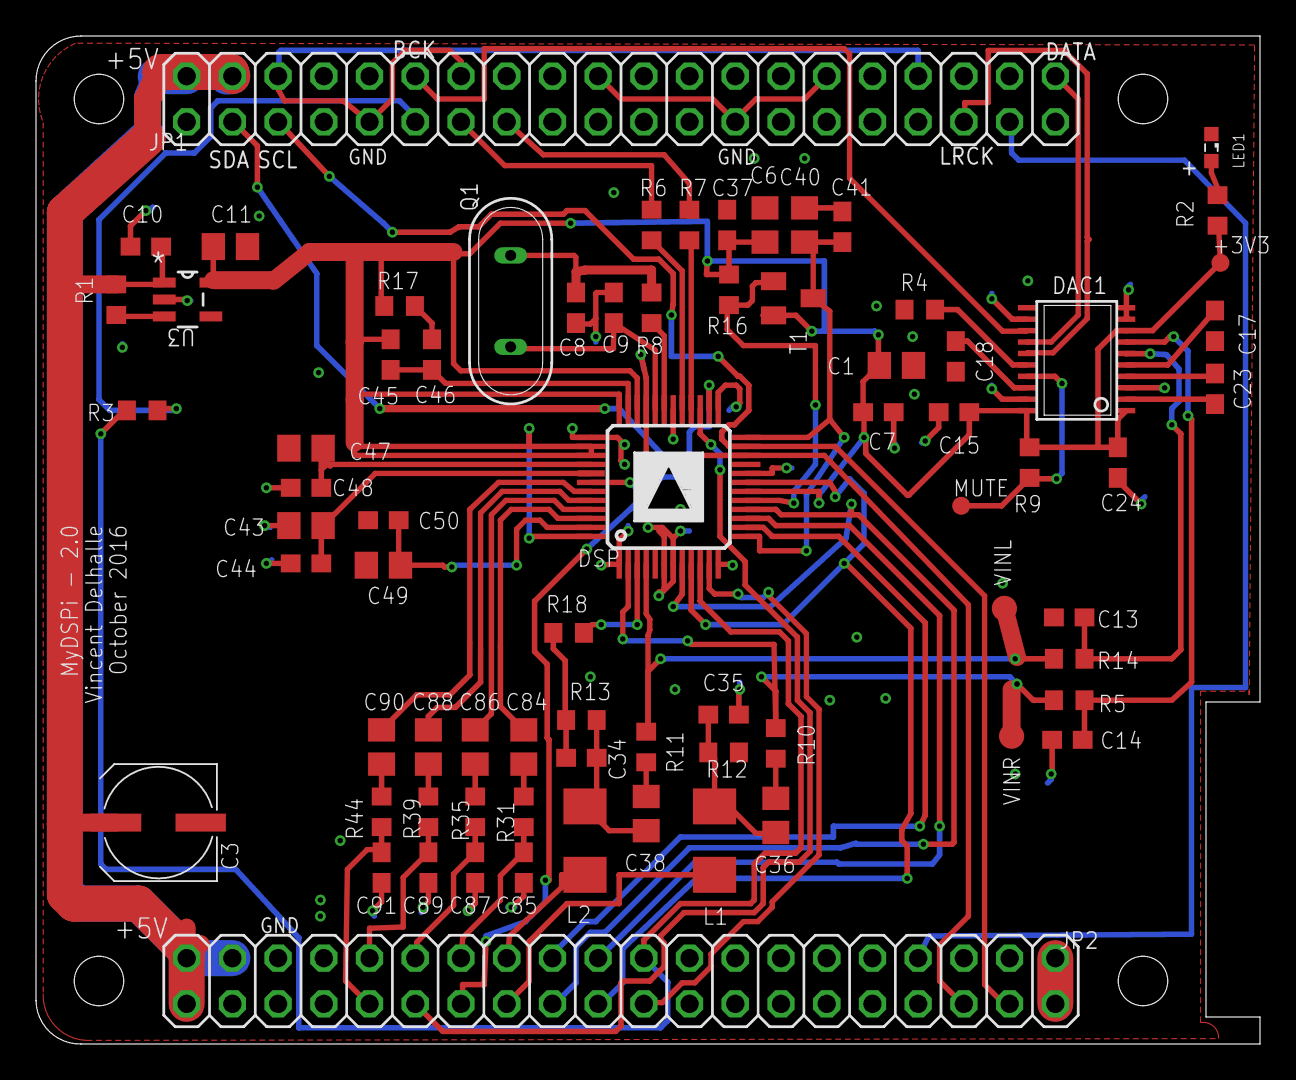
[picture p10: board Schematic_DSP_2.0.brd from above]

Board: 2 copper layers, 68.0 x 56.0 mm, 73 parts (0 on the bottom side), 65 nets.

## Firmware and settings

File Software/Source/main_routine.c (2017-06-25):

#include <stdio.h>
#include <fcntl.h>
#include <stdlib.h>
#include <unistd.h>
#include <sys/ioctl.h>
#include <string.h>
#include <errno.h>
#include <assert.h>
#include <sys/types.h>
#include <math.h>

//Error
#include "includes/error/error.h"

// Configuration
#include "config.h"

//I2C
#include <linux/i2c-dev.h>
#include "includes/libi2c/libi2c.h"

// DSP
#include "includes/Sigma/SS_MyDSPi_V122_IC_1.h"

#include "includes/Sigma/v122param.h"


#include "includes/DSP/DSPI2C.h"
#include "includes/DSP/DSPMath.h"

#include "includes/DSP/DSPDefine.h"
#include "includes/DSP/DSPBiquad.h"
#include "includes/Sigma/SigmaStudioFW.c"


//Ini manager

#include "includes/libini/libini.h"


#define PE_Address 0x40
#define DSP_Address 0x68

#define Master_Volume_Addr0 56
#define Master_Volume_Addr1 57
typedef unsigned long int UINT32;

#define PI 						3.141592654
#define Fs 						48000
#define MOD_CROSSOVER_20_ALG0_LOW_FILT1_PARAMB0_ADDR 90


void main(int argc, char *argv[])
{

struct f_return ret[5];
f_return i2cstatus;
f_return globalerr;



				 

printf("\n**********START Configuration of DSP *************\n");

i2cstatus = i2c_init("/dev/i2c-1");
	if(i2cstatus.errorstate !=-1)
	{
		//check device on i2c bus
		int i2cstatus = ADAU1701_Read_register(0x68,0x081C); 			
		if(i2cstatus>-1)
		{
		//Init DSP default values
		default_download_IC_1();


		int DSP_CORE_REG_VALUE = ADAU1701_Read_ConfigRegister(DSP_Address,0x081E);
		// printf("\n DSP CORE : 0x%X",DSP_CORE_REG_VALUE);
		

		/// To do: Mute all outputs and inputs
		//  

		// Check config file exist	
			FILE *fp;
			int filelenght;		
			char buffer[FILENAME_MAX];
			
			fp = fopen(config_file_path,"r");
			fread(buffer, filelenght, 1, fp); 
			
			if(fp == NULL)
			{
				globalerr = seterror(1,-1,"config file not found");
				exit(EXIT_FAILURE);
			}
			else
			{
				printf("\n Open config file %s : OK",config_file_path );
				char* pConfigurationFile;
				pConfigurationFile = malloc(filelenght*sizeof(char));
				pConfigurationFile = ReadFile(config_file_path);
			
		
			
				ret[0] = configure_DSP(pConfigurationFile);
				if(ret[0].errorstate!=-1)
				{
					printf("\n DSP configuration : OK >> %s", ret[0].errormessage);
				}
				else
				{
					printf("\n DSP configuration : Fail >> %s", ret[0].errormessage);
				}

				 ret[1] = configure_iochannels(pConfigurationFile);
				
				if(ret[1].errorstate!=-1)
				{
					printf("\n I/O configuration : OK");
					long int volume_value = ADAU1701_Read_register(0x68,MOD_MASTER_20_VOLUME_GAIN1940ALGNS1_ADDR);	
					float dBvalue = DectodB(volume_value); 
					printf(" DSP Master Volume: %f", dBvalue);		
				}
				else
				{
					printf("\n I/O configuration : Fail >> %s", ret[1].errormessage);
				}
	
				ret[3] = createcrossover(pConfigurationFile);
				if(ret[3].errorstate!=-1)
				{
					printf("\n Crossover configuration : OK");
				}
				else
				{
					printf("\n Crossover configuration : Fail >> %s",ret[3].errormessage);
				}
		
				ret[2] = createfilters(pConfigurationFile);
				if(ret[2].errorstate!=-1)
				{
					printf("\n EQ configuration : OK");
				}
				else
				{
					printf("\n EQ configuration : Fail >> %s", ret[2].errormessage);
				}

			}
		
		}



	}



printf("\n**********END Configuration of DSP *************\n");



}

	

		 
	



	

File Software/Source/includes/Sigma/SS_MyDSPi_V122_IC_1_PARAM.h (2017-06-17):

/*
 * File:           C:\Users\Vincent\Desktop\MyDSPI_20170413\SS_MyDSPi_V122\SS_MyDSPi_V122_IC_1_PARAM.h
 *
 * Created:        Monday, June 12, 2017 11:32:11 AM
 * Description:    SS_MyDSPi_V122:IC 1 parameter RAM definitions.
 *
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
 * This software may only be used to program products purchased from
 * Analog Devices for incorporation by you into audio products that
 * are intended for resale to audio product end users. This software
 * may not be distributed whole or in any part to third parties.
 *
 * Copyright ©2017 Analog Devices, Inc. All rights reserved.
 */
#ifndef __SS_MYDSPI_V122_IC_1_PARAM_H__
#define __SS_MYDSPI_V122_IC_1_PARAM_H__


/* Module Tone1 - Sine Tone*/
#define MOD_TONE1_COUNT                                3
#define MOD_TONE1_DEVICE                               "IC1"
#define MOD_STATIC_TONE1_ALG0_MASK_ADDR                0
#define MOD_STATIC_TONE1_ALG0_MASK_FIXPT               0x000000FF
#define MOD_STATIC_TONE1_ALG0_MASK_VALUE               SIGMASTUDIOTYPE_INTEGER_CONVERT(255)
#define MOD_STATIC_TONE1_ALG0_MASK_TYPE                SIGMASTUDIOTYPE_INTEGER
#define MOD_TONE1_ALG0_INCREMENT_ADDR                  1
#define MOD_TONE1_ALG0_INCREMENT_FIXPT                 0x0002AAAE
#define MOD_TONE1_ALG0_INCREMENT_VALUE                 SIGMASTUDIOTYPE_FIXPOINT_CONVERT(0.02083375)
#define MOD_TONE1_ALG0_INCREMENT_TYPE                  SIGMASTUDIOTYPE_FIXPOINT
#define MOD_TONE1_ALG0_ON_ADDR                         2
#define MOD_TONE1_ALG0_ON_FIXPT                        0x00800000
#define MOD_TONE1_ALG0_ON_VALUE                        SIGMASTUDIOTYPE_FIXPOINT_CONVERT(1)
#define MOD_TONE1_ALG0_ON_TYPE                         SIGMASTUDIOTYPE_FIXPOINT

/* Module Tone1_2 - Sine Tone*/
#define MOD_TONE1_2_COUNT                              3
#define MOD_TONE1_2_DEVICE                             "IC1"
#define MOD_STATIC_TONE1_2_ALG0_MASK_ADDR              3
#define MOD_STATIC_TONE1_2_ALG0_MASK_FIXPT             0x000000FF
#define MOD_STATIC_TONE1_2_ALG0_MASK_VALUE             SIGMASTUDIOTYPE_INTEGER_CONVERT(255)
#define MOD_STATIC_TONE1_2_ALG0_MASK_TYPE              SIGMASTUDIOTYPE_INTEGER
#define MOD_TONE1_2_ALG0_INCREMENT_ADDR                4
#define MOD_TONE1_2_ALG0_INCREMENT_FIXPT               0x001AAAAE
#define MOD_TONE1_2_ALG0_INCREMENT_VALUE               SIGMASTUDIOTYPE_FIXPOINT_CONVERT(0.20833375)
#define MOD_TONE1_2_ALG0_INCREMENT_TYPE                SIGMASTUDIOTYPE_FIXPOINT
#define MOD_TONE1_2_ALG0_ON_ADDR                       5
#define MOD_TONE1_2_ALG0_ON_FIXPT                      0x00800000
#define MOD_TONE1_2_ALG0_ON_VALUE                      SIGMASTUDIOTYPE_FIXPOINT_CONVERT(1)
#define MOD_TONE1_2_ALG0_ON_TYPE                       SIGMASTUDIOTYPE_FIXPOINT

/* Module Channel_20_Merger_2 - Signal Merger*/
#define MOD_CHANNEL_20_MERGER_2_COUNT                  1
#define MOD_CHANNEL_20_MERGER_2_DEVICE                 "IC1"
#define MOD_CHANNEL_20_MERGER_2_SINGLECTRLMIXER19401_ADDR 6
#define MOD_CHANNEL_20_MERGER_2_SINGLECTRLMIXER19401_FIXPT 0x00400000
#define MOD_CHANNEL_20_MERGER_2_SINGLECTRLMIXER19401_VALUE SIGMASTUDIOTYPE_FIXPOINT_CONVERT(0.5)
#define MOD_CHANNEL_20_MERGER_2_SINGLECTRLMIXER19401_TYPE SIGMASTUDIOTYPE_FIXPOINT

/* Module Signal_Selector_20 - Stereo Switch Nx2*/
#define MOD_SIGNAL_SELECTOR_20_COUNT                   3
#define MOD_SIGNAL_SELECTOR_20_DEVICE                  "IC1"
#define MOD_SIGNAL_SELECTOR_20_ALG0_STAGE0_STEREOSWITCHNOSLEW_ADDR 7
#define MOD_SIGNAL_SELECTOR_20_ALG0_STAGE0_STEREOSWITCHNOSLEW_FIXPT 0x00800000
#define MOD_SIGNAL_SELECTOR_20_ALG0_STAGE0_STEREOSWITCHNOSLEW_VALUE SIGMASTUDIOTYPE_FIXPOINT_CONVERT(1)
#define MOD_SIGNAL_SELECTOR_20_ALG0_STAGE0_STEREOSWITCHNOSLEW_TYPE SIGMASTUDIOTYPE_FIXPOINT
#define MOD_SIGNAL_SELECTOR_20_ALG0_STAGE1_STEREOSWITCHNOSLEW_ADDR 8
#define MOD_SIGNAL_SELECTOR_20_ALG0_STAGE1_STEREOSWITCHNOSLEW_FIXPT 0x00000000
#define MOD_SIGNAL_SELECTOR_20_ALG0_STAGE1_STEREOSWITCHNOSLEW_VALUE SIGMASTUDIOTYPE_FIXPOINT_CONVERT(0)
#define MOD_SIGNAL_SELECTOR_20_ALG0_STAGE1_STEREOSWITCHNOSLEW_TYPE SIGMASTUDIOTYPE_FIXPOINT
#define MOD_SIGNAL_SELECTOR_20_ALG0_STAGE2_STEREOSWITCHNOSLEW_ADDR 9
#define MOD_SIGNAL_SELECTOR_20_ALG0_STAGE2_STEREOSWITCHNOSLEW_FIXPT 0x00000000
#define MOD_SIGNAL_SELECTOR_20_ALG0_STAGE2_STEREOSWITCHNOSLEW_VALUE SIGMASTUDIOTYPE_FIXPOINT_CONVERT(0)
#define MOD_SIGNAL_SELECTOR_20_ALG0_STAGE2_STEREOSWITCHNOSLEW_TYPE SIGMASTUDIOTYPE_FIXPOINT

/* Module Mute L - Mute*/
#define MOD_MUTEL_COUNT                                1
#define MOD_MUTEL_DEVICE                               "IC1"
#define MOD_MUTEL_MUTENOSLEWALG6MUTE_ADDR              10
#define MOD_MUTEL_MUTENOSLEWALG6MUTE_FIXPT             0x00800000
#define MOD_MUTEL_MUTENOSLEWALG6MUTE_VALUE             SIGMASTUDIOTYPE_FIXPOINT_CONVERT(1)
#define MOD_MUTEL_MUTENOSLEWALG6MUTE_TYPE              SIGMASTUDIOTYPE_FIXPOINT
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

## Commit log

2017-06-17 Electronic part first commit
    [Schematic_DSP_2.0.GBL, Schematic_DSP_2.0.GBO, Schematic_DSP_2.0.GBP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]
2017-06-17 amplification board
    [Schematic_Amplifier_2.0.0.GBL, Schematic_Amplifier_2.0.0.GBO, Schematic_Amplifier_2.0.0.GBP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]

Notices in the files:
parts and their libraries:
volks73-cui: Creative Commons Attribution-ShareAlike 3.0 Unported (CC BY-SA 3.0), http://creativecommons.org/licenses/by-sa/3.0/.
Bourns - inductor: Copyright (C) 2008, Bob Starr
